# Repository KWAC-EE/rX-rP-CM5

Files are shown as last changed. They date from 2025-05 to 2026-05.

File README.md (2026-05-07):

## rX-rP-CM5 ##
**Radxa-rPi CM5 Compatibility Layer**






The Radxa and RaspberryPi CM5s have much in common, but the pinout between them differs. Functionally, the Radxa's RK3588 outperforms Broadcom's BCM2712 in most benchmarks (at least those i'm interested in):
[Benchmarks seen here](https://gadgetversus.com/processor/rockchip-rk3588s-vs-broadcom-bcm2712/)

Native GPU video encode and decode makes the Radxa far more ideal to use as the core of a media server, and local AI acceleration should allow a more energy efficient means of driving my smarthome devices without needing to ping a distal server.

Physically, the Radxa CM5 is more compatible with rPi CM4 carriers than it is with those built for the rPiCM5.
The CM4 wasn't received as enthusatically by developers as the CM5, so more custom carriers are being built to take advantage of the added USB3 functionality.
For that reason, i designed an adapter to transpose the USB3 lanes from the auxilary mezzanine connector on the Radxa to the corresponding pinout on the RaspberryPi variant.

This design includes automatic switching via MUX so the transposed lanes are allocated properly during flashing vs normal operation. CC resistors & VBus_Enable pull-ups have been added for designs which use those pins.

# Project design files
PCBAs are designed in Altium 22 & 25. This is a paid software platform for professionals, and viewer licenses can be requested from the developers.

Design references can also be found as PDFs for those who wish to rebuild segments of the design themselves.

# PCBA exports/ Manufacturer files
Designs have been exported as Gerbers with Pick&Place & BOM files such that they may be fully assembled by prototypers such as JLC-PCB, PCB-Way and the like.
Simply upload the zipped project export folder for the PCB, then the internal XLXS/CSV component-level assembly.

# License
Copyright Kurt Widhalm/@KWAC-EE 2025
This source describes Open Hardware and is licensed under the CERN-OHL-P v2

You may redistribute and modify this documentation and make products using it under the terms of the CERN-OHL-P v2 (https:/cern.ch/cern-ohl). This documentation is distributed WITHOUT ANY EXPRESS OR IMPLIED WARRANTY, INCLUDING OF MERCHANTABILITY, SATISFACTORY QUALITY AND FITNESS FOR A PARTICULAR PURPOSE. Please see the CERN-OHL-P v2 for applicable conditions

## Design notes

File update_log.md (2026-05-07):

*10/16/2025*
Samples of X2 arrived, as did a fresh CM5 from Radxa.
As hoped, the USB-C port allows the device to be programmed independently.
There are a few bugs in the transposition, at least in the carrier I design to pair with this.
The primary USB3 lane from the auxilary port is transposed to the USB3-1 channel pads of the Raspberry pi CM5 carrier, and downstream devices fully enumerate and function.
The USB-C channel, however, doesn't appear to be behaving correctly, at least not on my current OS & hardware.
Similarly, the USB2 lane that is transposed to the OTG pads doesn't appear to initialize the downstream hub.
I'll continue testing by using a real CM5 IO board from raspberry pi soon.

**<11:30pm>**
ok, I know what I did now. flipped the polarity between the otg & USB-C d+/- nets. dislexia strikes again...

you know what they say: third rev's the charm. dammit....

*11/17/2025*
X3 samples are in. USB2 and USB3-1 channels work as intended, and the onboard USB-C(2.0) port allows flashing of the module; USB3-0, which is derived from the Type-C on header J3, will not enumerate connected devices through OTG/Host mode. May be from I2C port controller, still debugging

*2/20/2026*
X4 design is done. giving up on using the OTG port to drive a separate USB3 channel, and instead decided to split the known working USB3 channel with a hub. Will this reduce overall bandwidth? Yes, but for my application, i doubt it will be noticable.
I'll order samples when i place another order for other parts.

*3/27/2026*
Shouldn't have given up on X3 so quickly... Did a bit more experimenting. Lo and Behold, i needed to depop the FUSB chip completely, enter the Radxa OS configuration utility and manually set the OTG port to use only Host mode, and Tah-dah, it works exactly as intended. which is good, because there seems to be some interference caused by the hub on the X4 version that prevents the flashing utility from conntecting to the Emmc. So if you were planning on using any version of this design, i recommend starting from X3, removing the FUSB U1 component, and configuring it within the device tree.

*5/7/2026*
I just widdled it down for rev X5 to make use of what I learned from working on X3. Mechanically, the addition of the USB-C port was a hinderance; it got in the way of a few hardware enclosures, so i wasn't cleanly able to test compatibility with some custom carriers.
Electrically, i think the MUX config will function better so I can flash the EEprom of the SoM without the extra connector. Furthermore, i needed to add pull-ups for the VBus-enable pin so the current regulator on the Pi Cm5 IO board would turn on without bodging at start-up.
IDk when i'll be able to order samples. I really want to deploy one of these units so i can set up my Arm64 Nas, but the expense is hard to justify without additional parts to order with it.

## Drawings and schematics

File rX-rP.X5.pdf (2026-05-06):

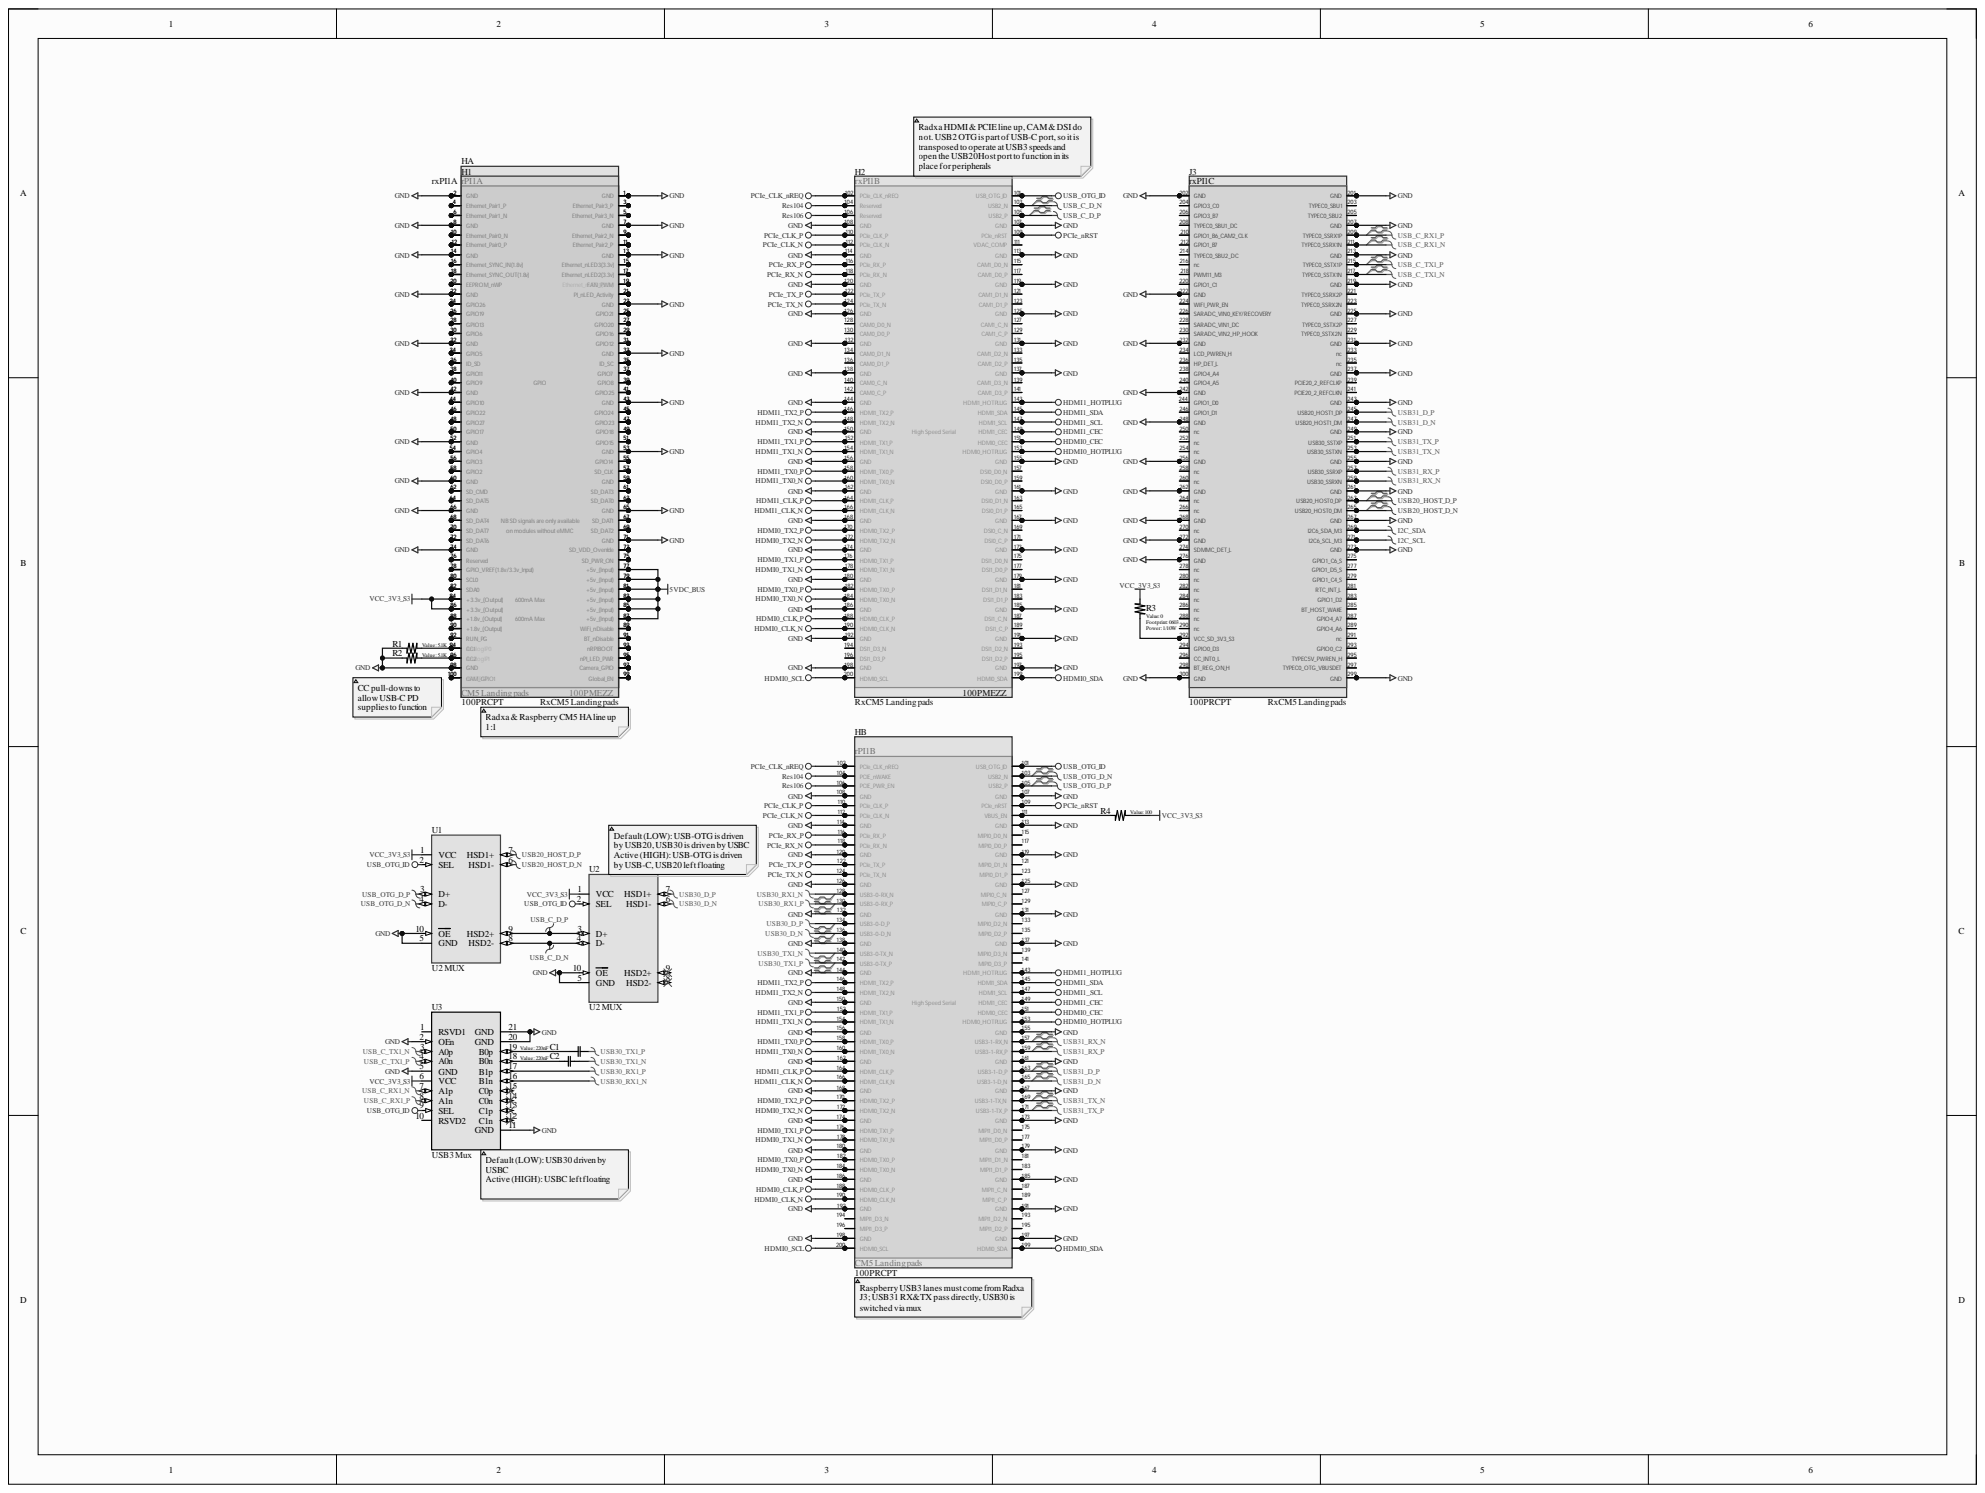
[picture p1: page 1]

Radxa HDMI &PCIEline up,CAM&DSI do
not. USB2 OTG is part of USB-C port,so itis
transposed to operate atUSB3 speeds and
open the USB20Hostportto function in its
place for peripherals

NB SD signals are only available

on modules without eMMC

Default(LOW):USB-OTG is driven
by USB20, USB30 is driven by USBC
Active (HIGH):USB-OTG is driven
by USB-C,USB20 leftfloating

Default(LOW):USB30 driven by
USBC
Active (HIGH):USBC leftfloating

CM5 Landingpads
100PRCPT
Raspberry USB3 lanesmust come fromRadxa
J3;USB31RX&TX pass directly, USB30 is
switched via mux

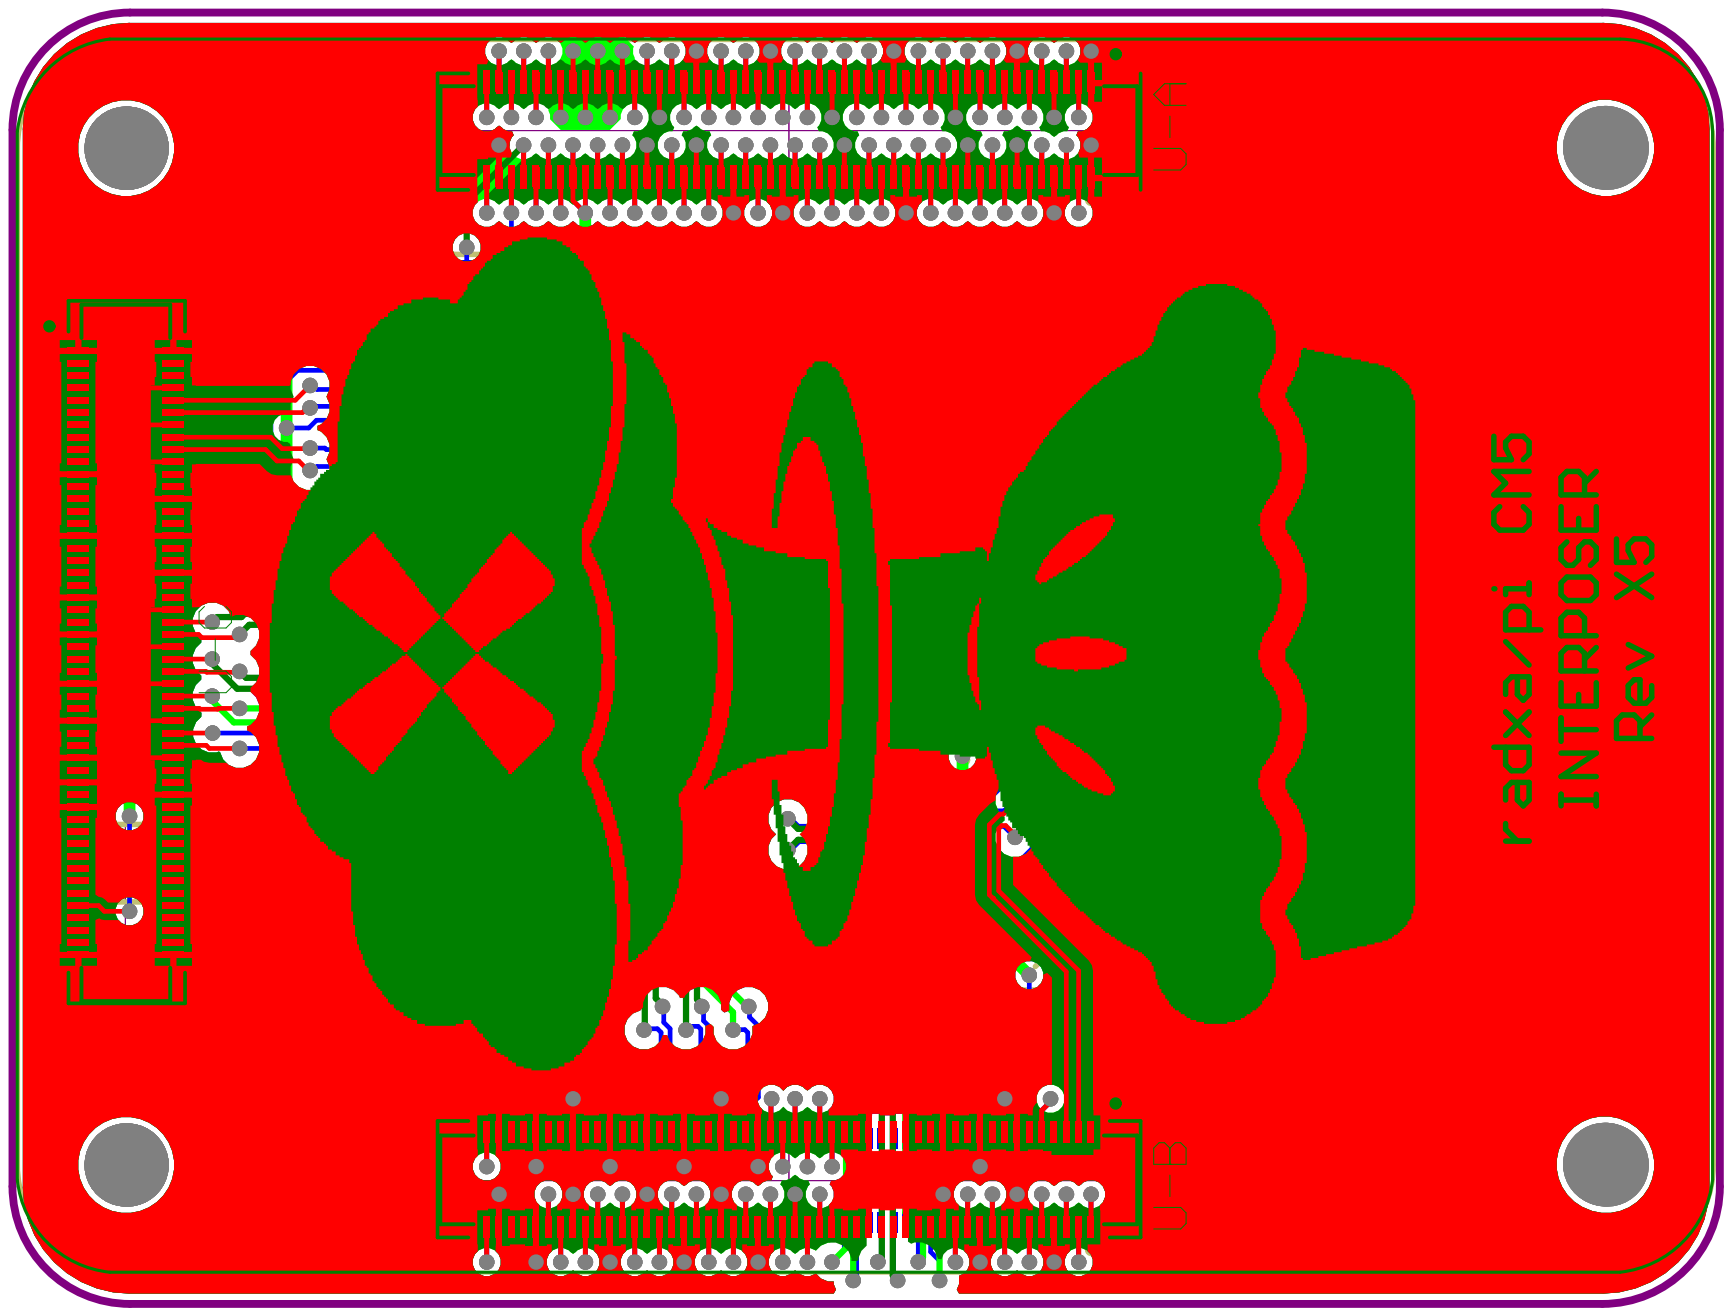
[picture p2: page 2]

Designator | Footprint | Value | LCSCPN
C1 | 0603 | 220nF
C2 | 0603 | 220nF
H1 | DF40C-100DS-0.4V(51) | | C597931
H2 | DF40C-100DS-0.4V(51) | | C597931
HA | DF40C-100DP-0.4V(51) | | C19089239
HB | DF40C-100DP-0.4V(51) | | C19089239
J3 | DF40C-100DS-0.4V(51) | | C597931
R1 | 0603 | 5.1K
R2 | 0603 | 5.1K
R3 | 0603 | 0
R4 | 0603 | 100
rPI1 | rP-200P-CM-REP(top)
rxPI1 | RX-300P-CM-FTPD
U1 | MSOP-10 | | C11355
U2 | MSOP-10 | | C11355
U3 | QFN50P450X250X100-21N | | C2869871

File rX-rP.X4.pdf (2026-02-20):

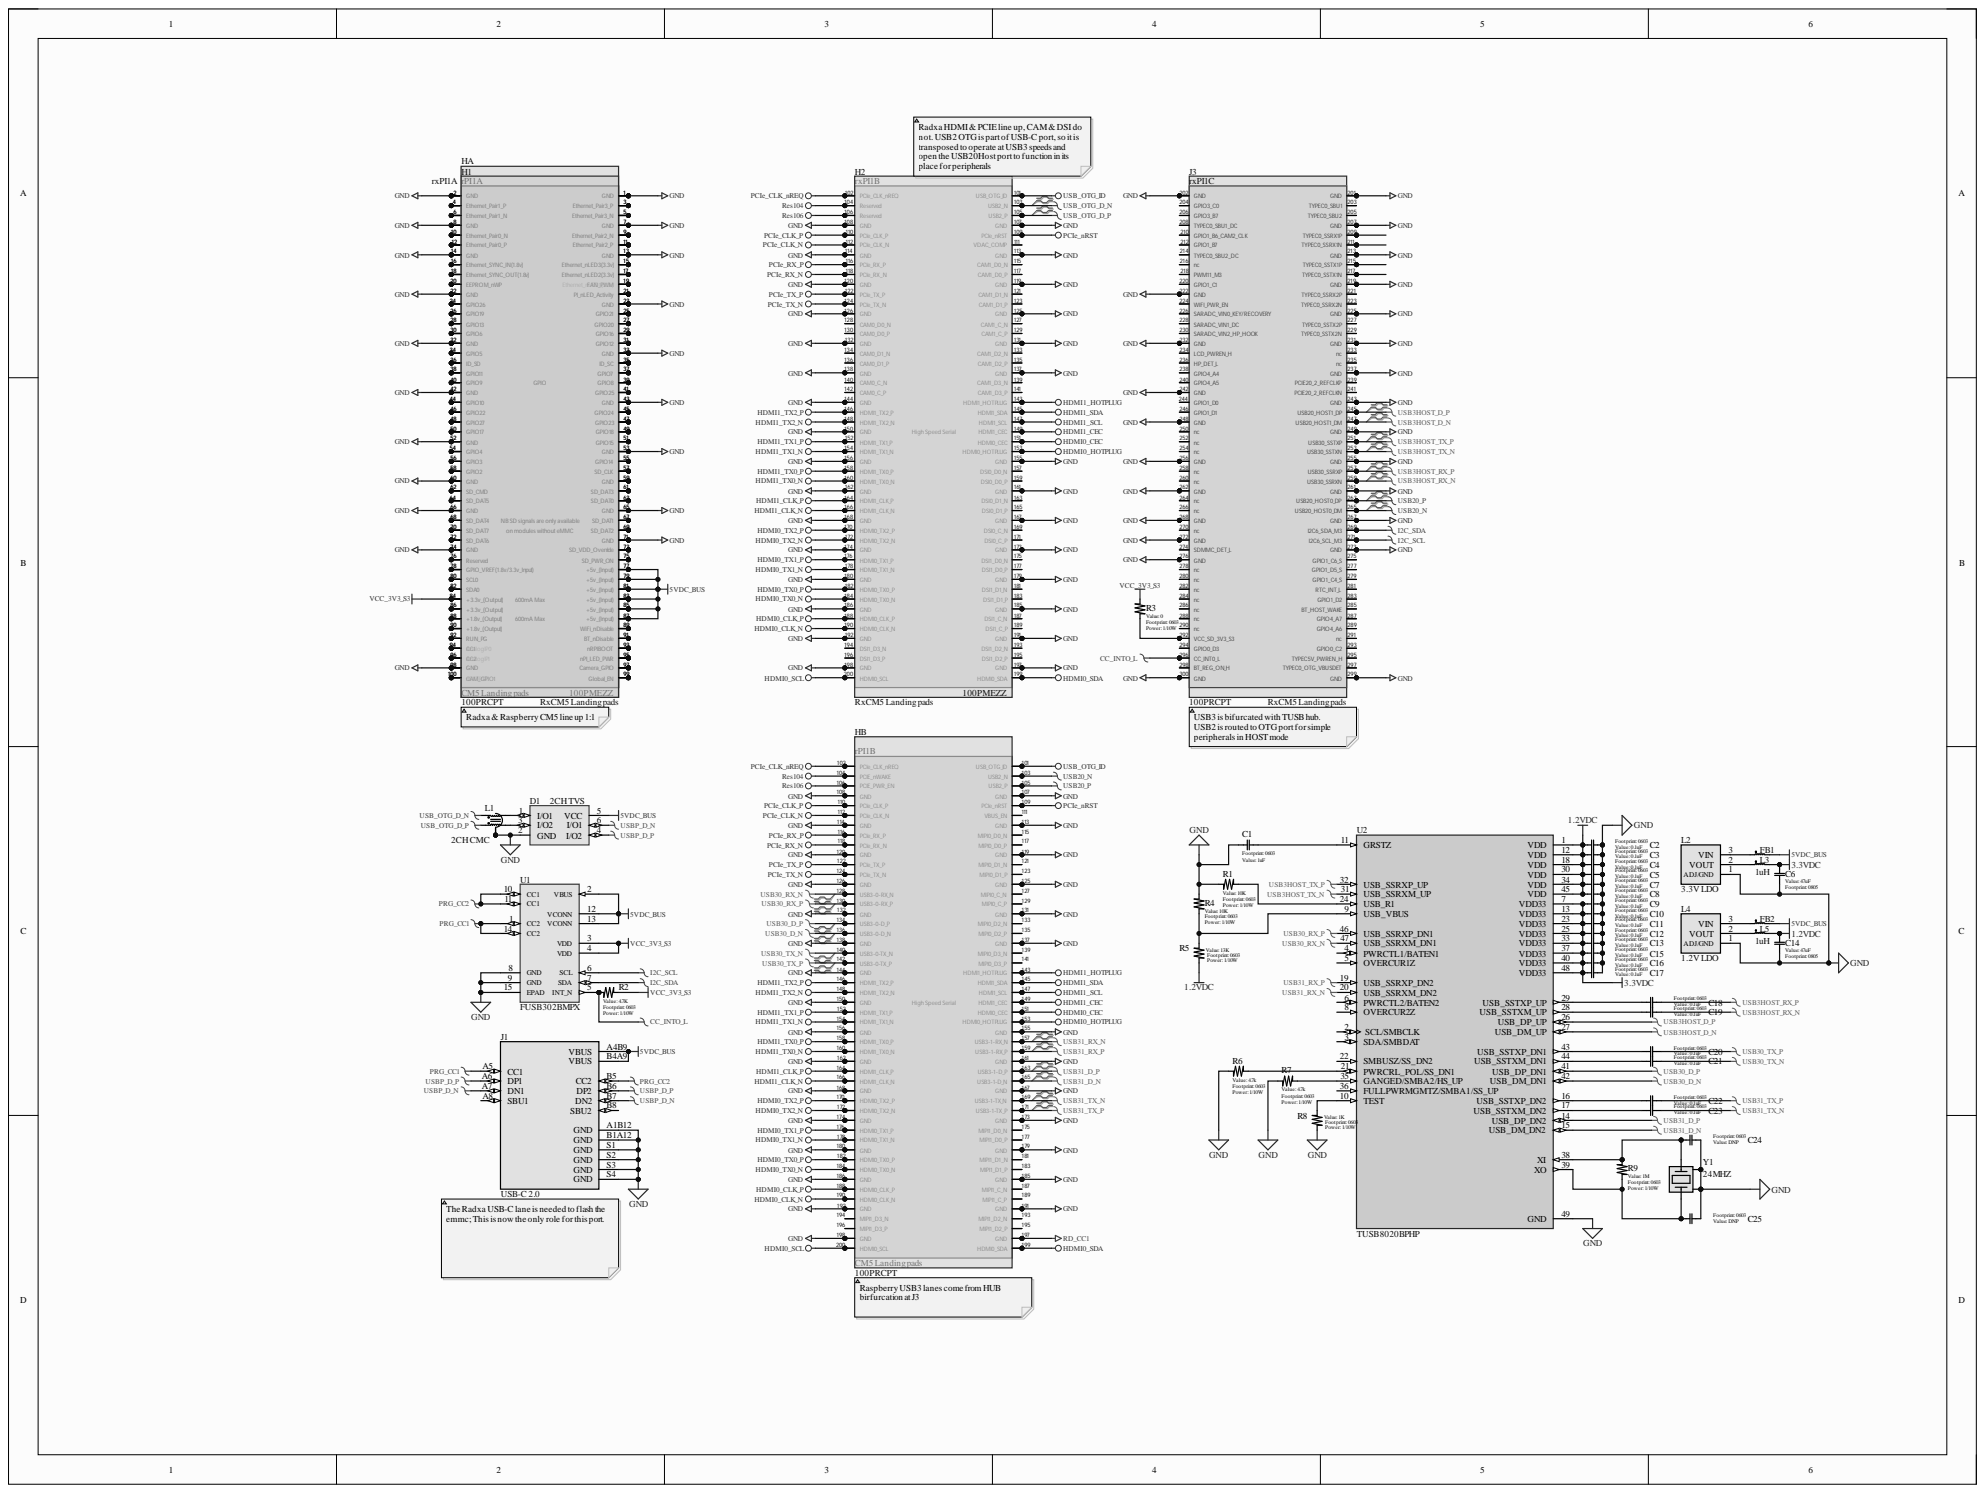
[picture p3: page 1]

GND GND GND GND GND GND GND GND GND GND GND

GND GND GND GND GND GND GND GND GND

GND GND GND GND GND GND GND

GND GND GND GND GND GND GND GND

GND GND GND GND GND GND GND GND GND GND GND GND GND

GND GND GND GND GND GND GND GND GND GND GND GND HDMI0_

GND GND GND GND GND GND GND GND GND GND GND GND GND GND GND

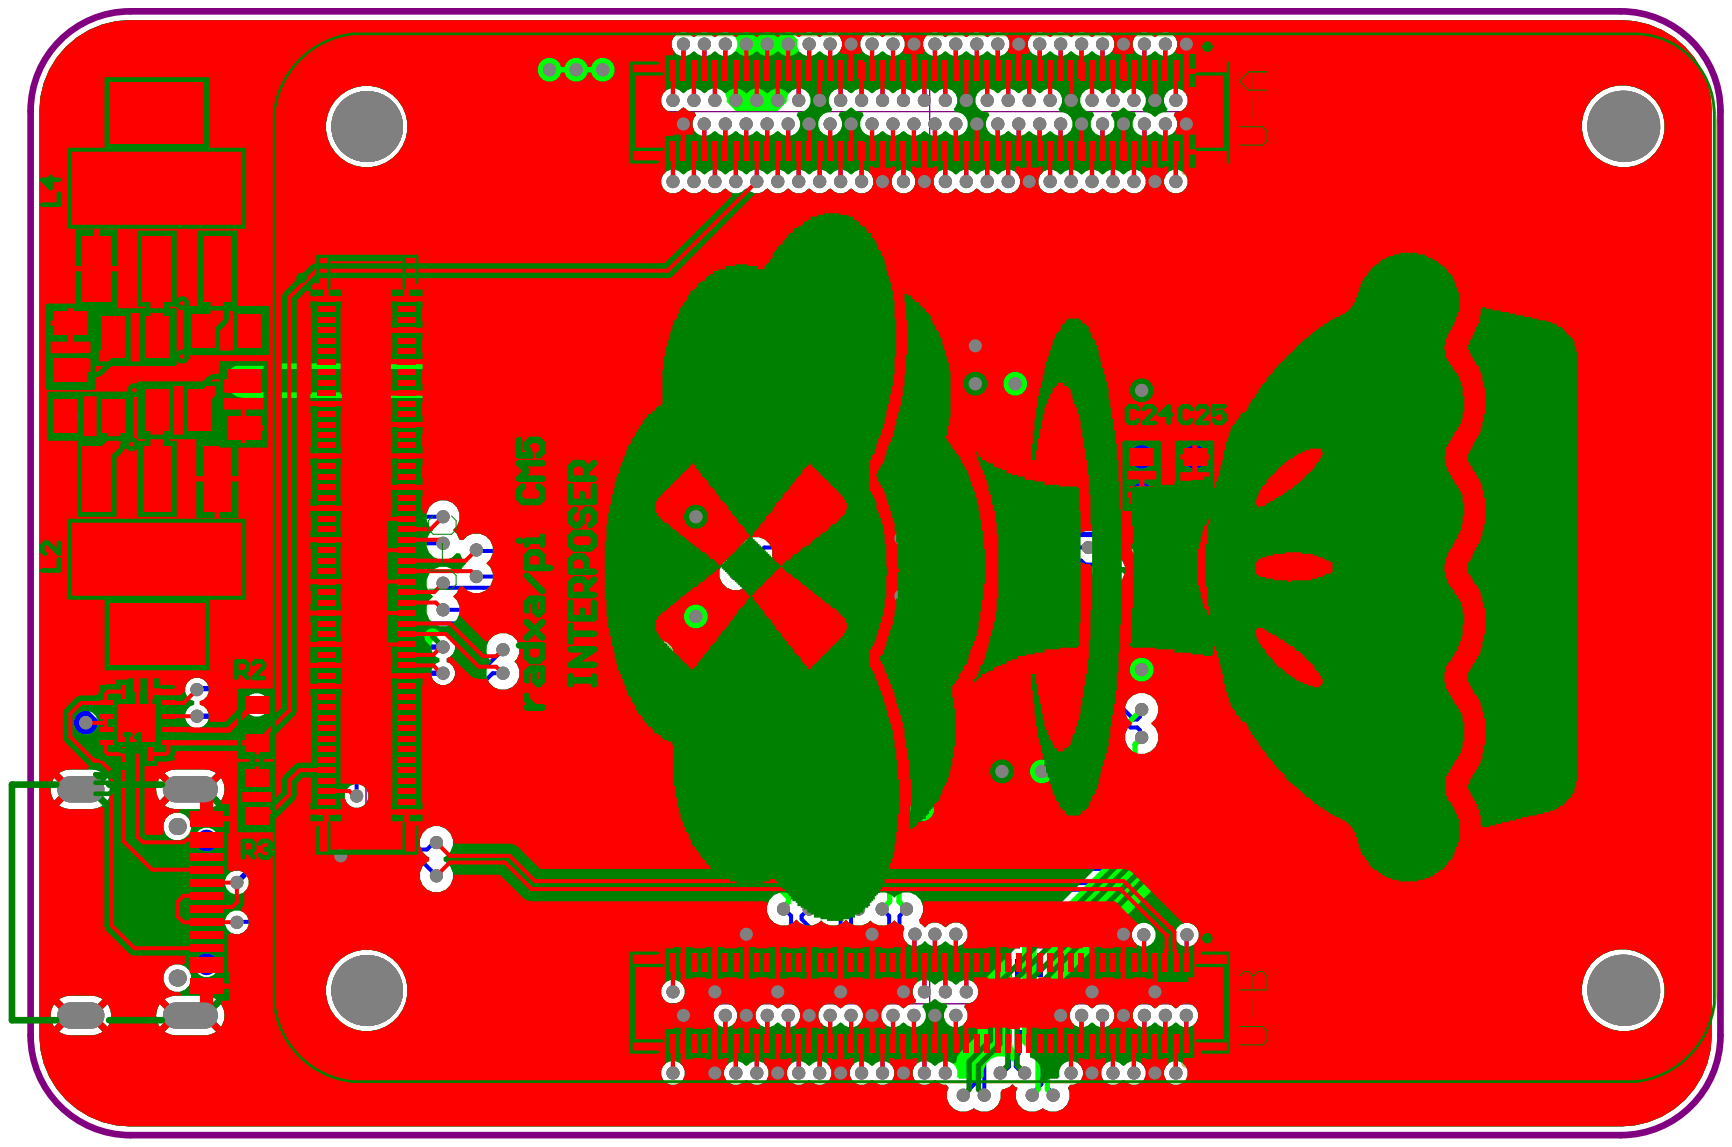
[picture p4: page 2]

Designator | Footprint | Value | LCSCPN
C1 | 0603 | 1uF
C2 | 0603 | 0.1uF
C3 | 0603 | 0.1uF
C4 | 0603 | 0.1uF
C5 | 0603 | 0.1uF
C6 | 0805 | 47uF
C7 | 0603 | 0.1uF
C8 | 0603 | 0.1uF
C9 | 0603 | 0.1uF
C10 | 0603 | 0.1uF
C11 | 0603 | 0.1uF
C12 | 0603 | 0.1uF
C13 | 0603 | 0.1uF
C14 | 0805 | 47uF
C15 | 0603 | 0.1uF
C16 | 0603 | 0.1uF
C17 | 0603 | 0.1uF
C18 | 0603 | 0.1uF
C19 | 0603 | 0.1uF
C20 | 0603 | 0.1uF
C21 | 0603 | 0.1uF
C22 | 0603 | 0.1uF
C23 | 0603 | 0.1uF
C24 | 0603 | DNP
C25 | 0603 | DNP
D1 | FP-SOT886-MFG | 1pF | C478118
FB1 | 0805
FB2 | 0805
H1 | DF40C-100DS-0.4V(51) | | C597931
H2 | DF40C-100DS-0.4V(51) | | C597931
HA | DF40C-100DP-0.4V(51) | | C19089239
HB | DF40C-100DP-0.4V(51) | | C19089239
J1 | GT-USB-7010ASV | | C2988369
J3 | DF40C-100DS-0.4V(51) | | C597931
L1 | SMD-6-2CH | | C396460
L2 | SOT-223-3 | | C326523
L3 | 0806
L4 | SOT-223-3 | | C277890
L5 | 0806
R1 | 0603 | 10K
R2 | 0603 | 4.7K
R3 | 0603 | 0
R4 | 0603 | 10K
R5 | 0603 | 13K
R6 | 0603 | 4.7k
R7 | 0603 | 4.7k
R8 | 0603 | 1K
R9 | 0603 | 1M
rPI1 | rP-200P-CM-REP(top)
rxPI1 | RX-300P-CM-FTPD
U1 | MLP14_2P5X2P5_ONS-L | | C132291
U2 | HTQFP-48(7x7) | | C205982
Y1 | SMD2520-4P | | C7294628
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

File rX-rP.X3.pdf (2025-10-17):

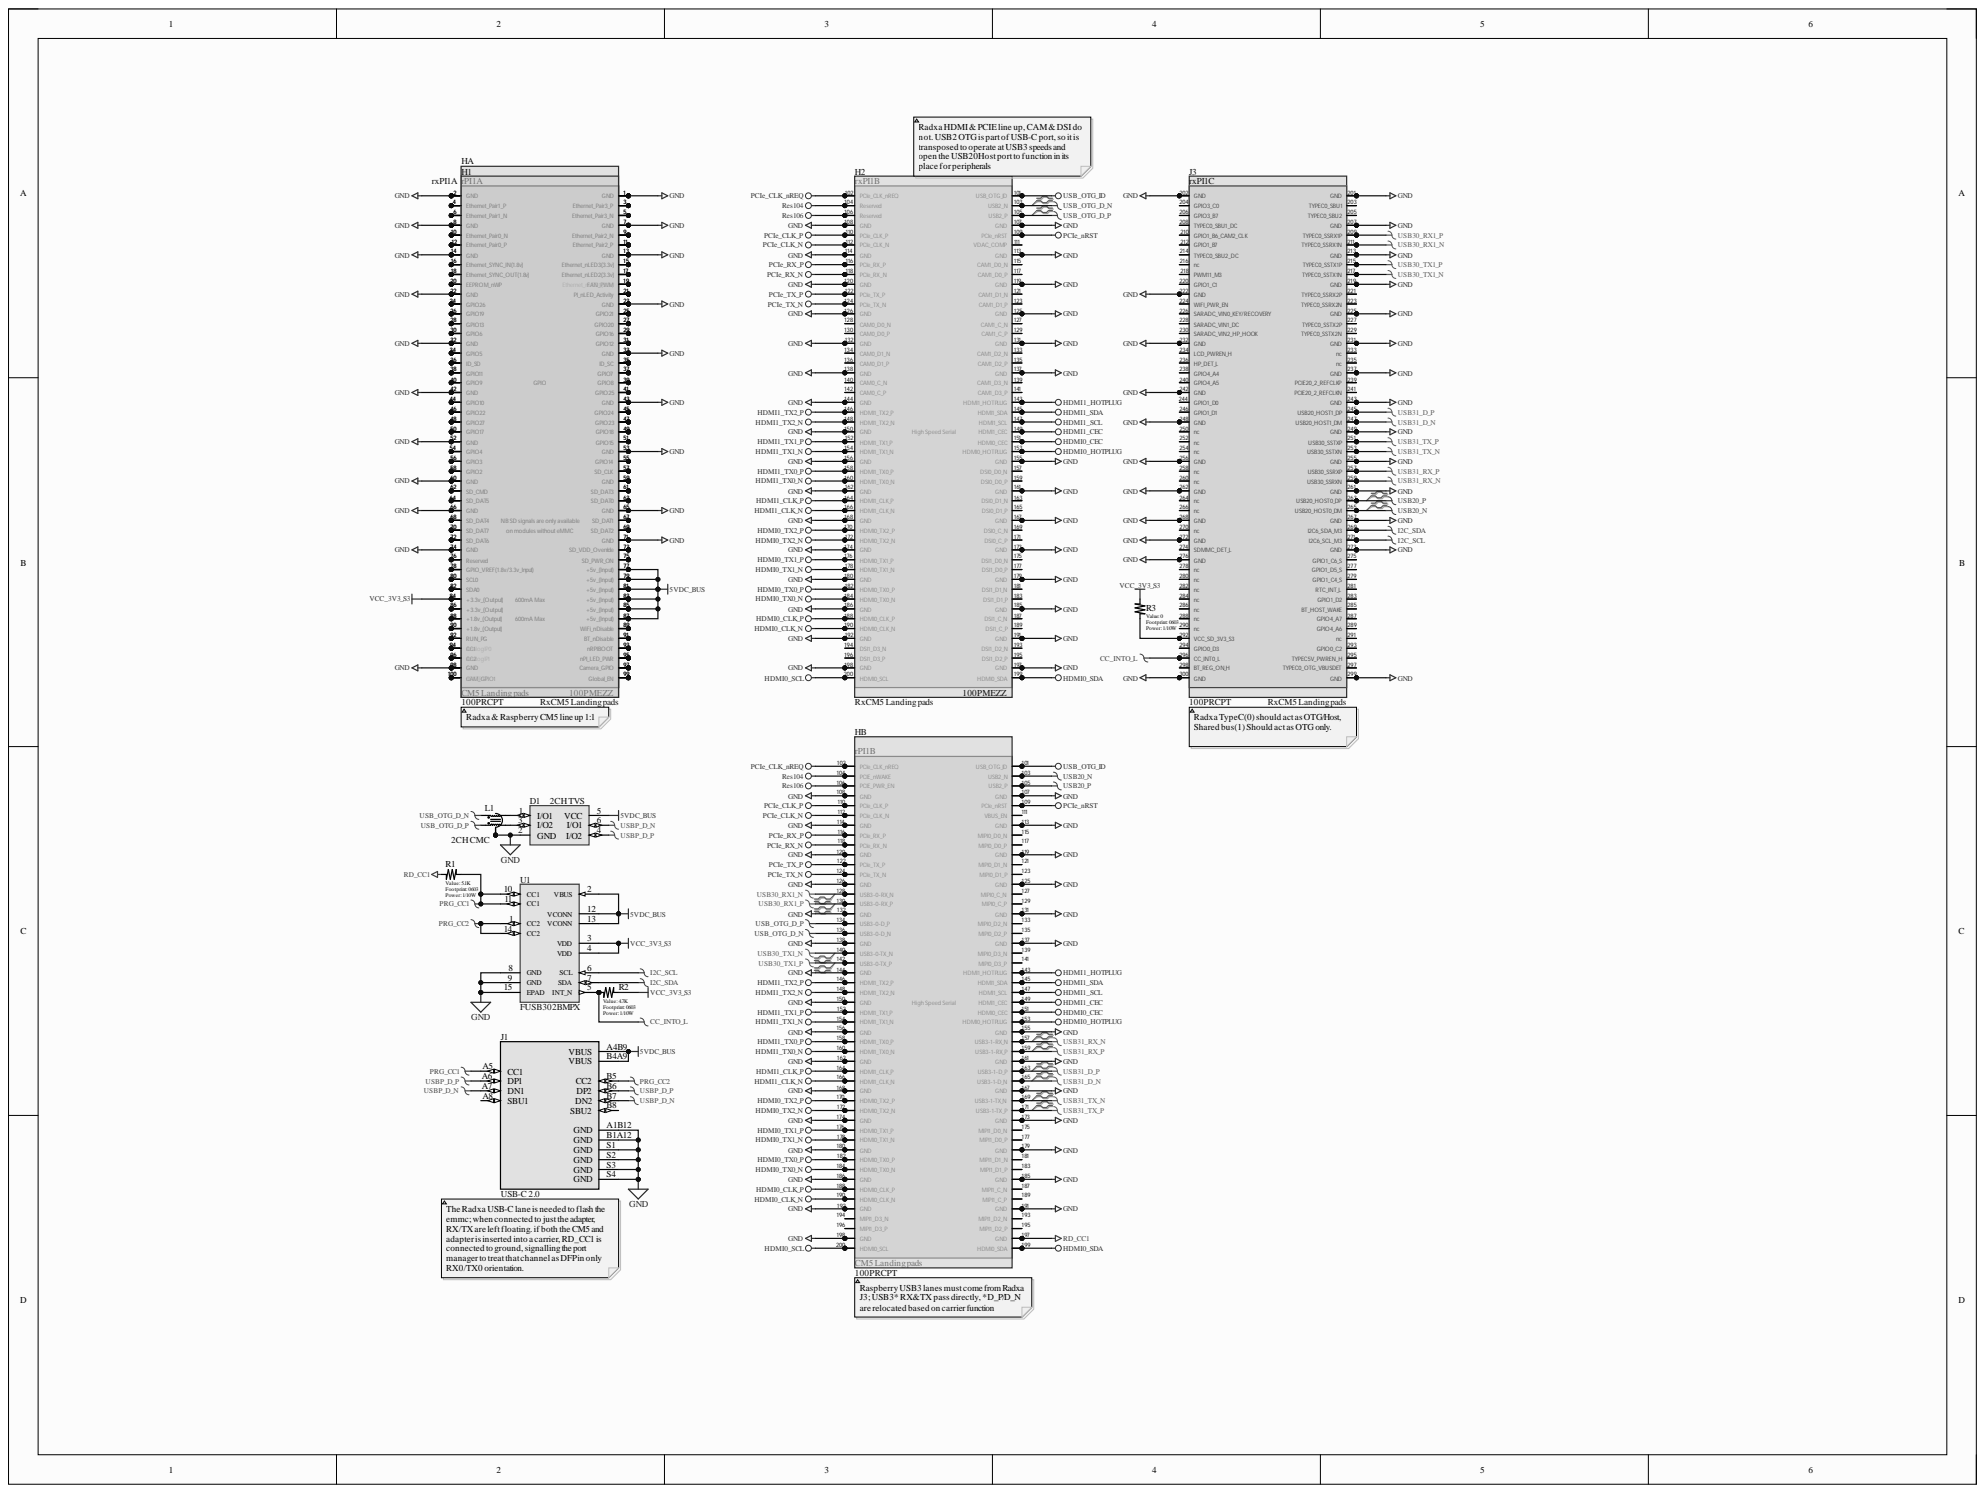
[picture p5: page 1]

Radxa HDMI &PCIEline up,CAM&DSI do
not. USB2 OTG is part of USB-C port,so itis
transposed to operate atUSB3 speeds and
open the USB20Hostportto function in its
place for peripherals

NB SD signals are only available

on modules without eMMC

100PRCPT
Radxa TypeC(0) should act asOTG/Host,
Shared bus(1) Should act asOTG only.

TheRadxa USB-C lane is needed to flash the
emmc;when connected to justthe adapter,
RX/TX are leftfloating. if both theCM5 and
adapter isinserted into a carrier,RD_CC1 is
connected to ground,signallingthe port
manager to treatthat channel asDFPin only
RX0/TX0 orientation.

CM5 Landingpads
Raspberry USB3 lanesmust come fromRadxa
J3;USB3*RX&TX pass directly, *D_P/D_N
are relocated based on carrier function

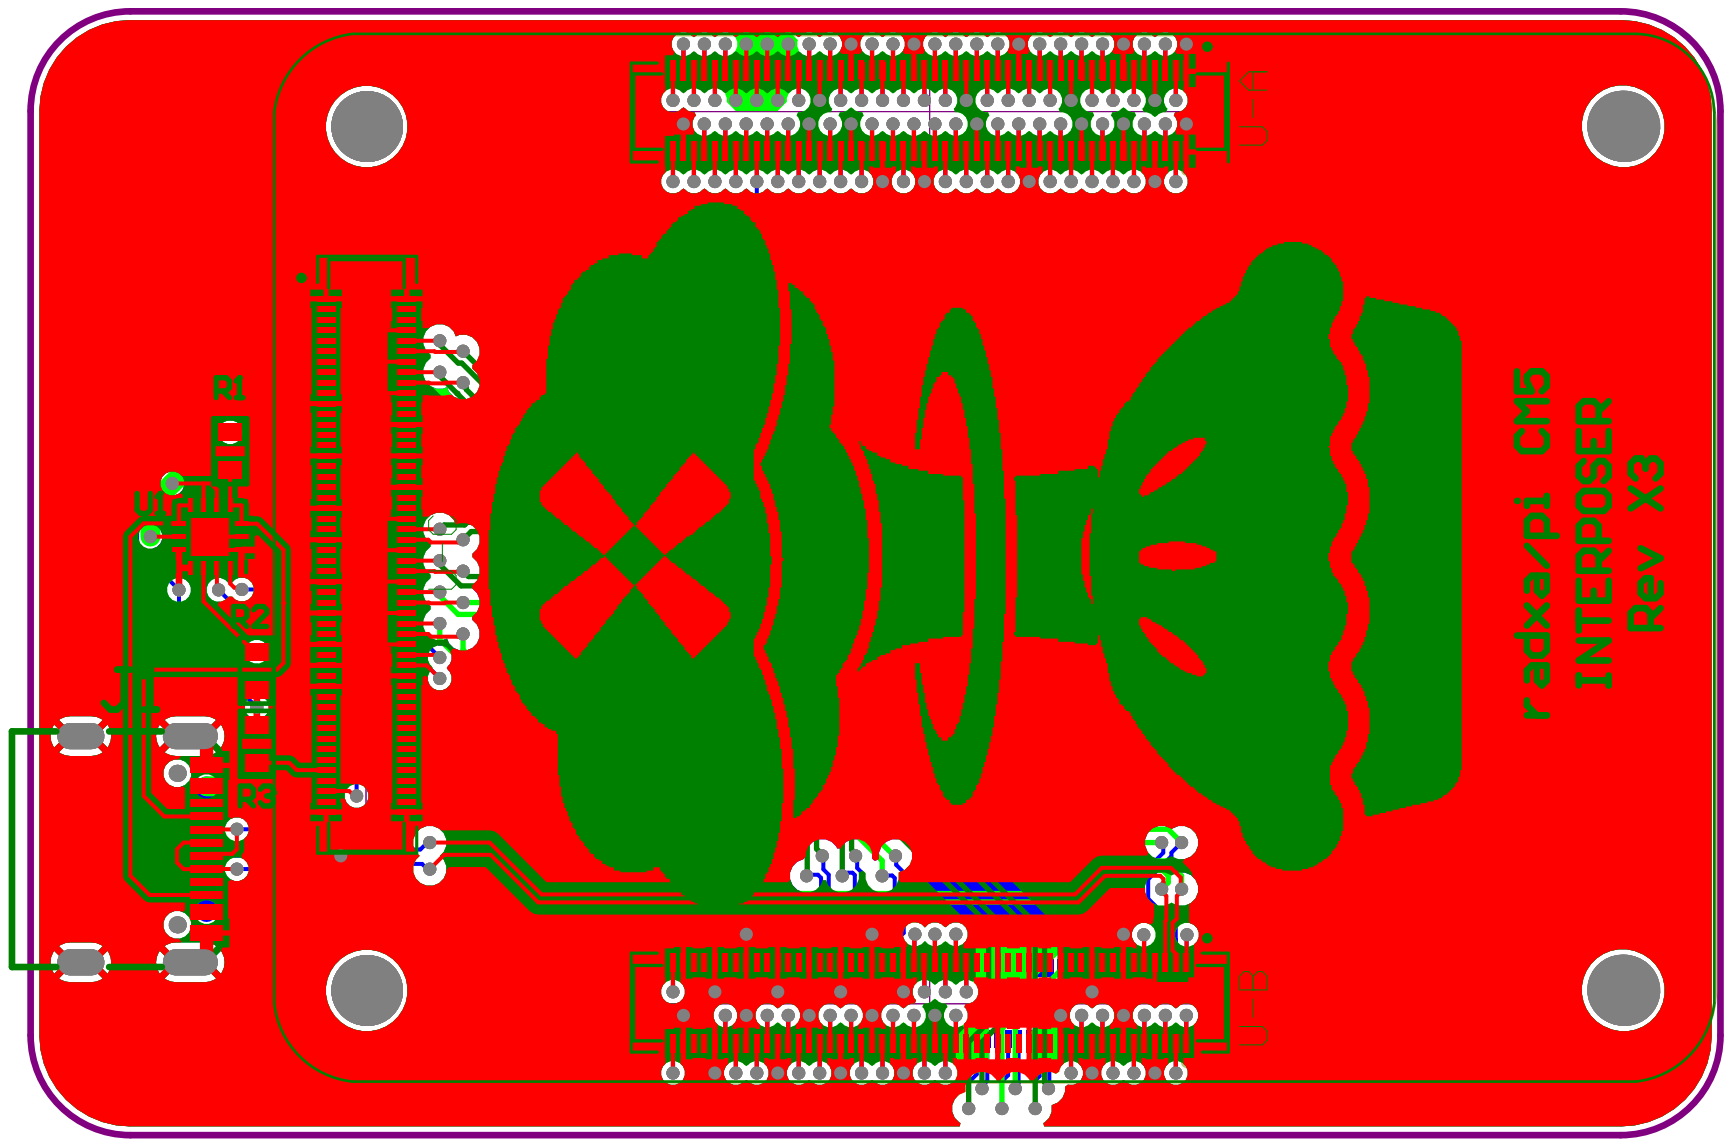
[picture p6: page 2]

Designator | Footprint | Value | LCSCPN
D1 | FP-SOT886-MFG | 1pF | C478118
H1 | DF40C-100DS-0.4V(51) | | C597931
H2 | DF40C-100DS-0.4V(51) | | C597931
HA | DF40C-100DP-0.4V(51) | | C19089239
HB | DF40C-100DP-0.4V(51) | | C19089239
J1 | GT-USB-7010ASV | | C2988369
J3 | DF40C-100DS-0.4V(51) | | C597931
L1 | SMD-6-2CH | | C396460
R1 | 0603 | 5.1K
R2 | 0603 | 4.7K
R3 | 0603 | 0
rPI1 | rP-200P-CM-REP(top)
rxPI1 | RX-300P-CM-FTPD
U1 | MLP14_2P5X2P5_ONS-L | | C132291

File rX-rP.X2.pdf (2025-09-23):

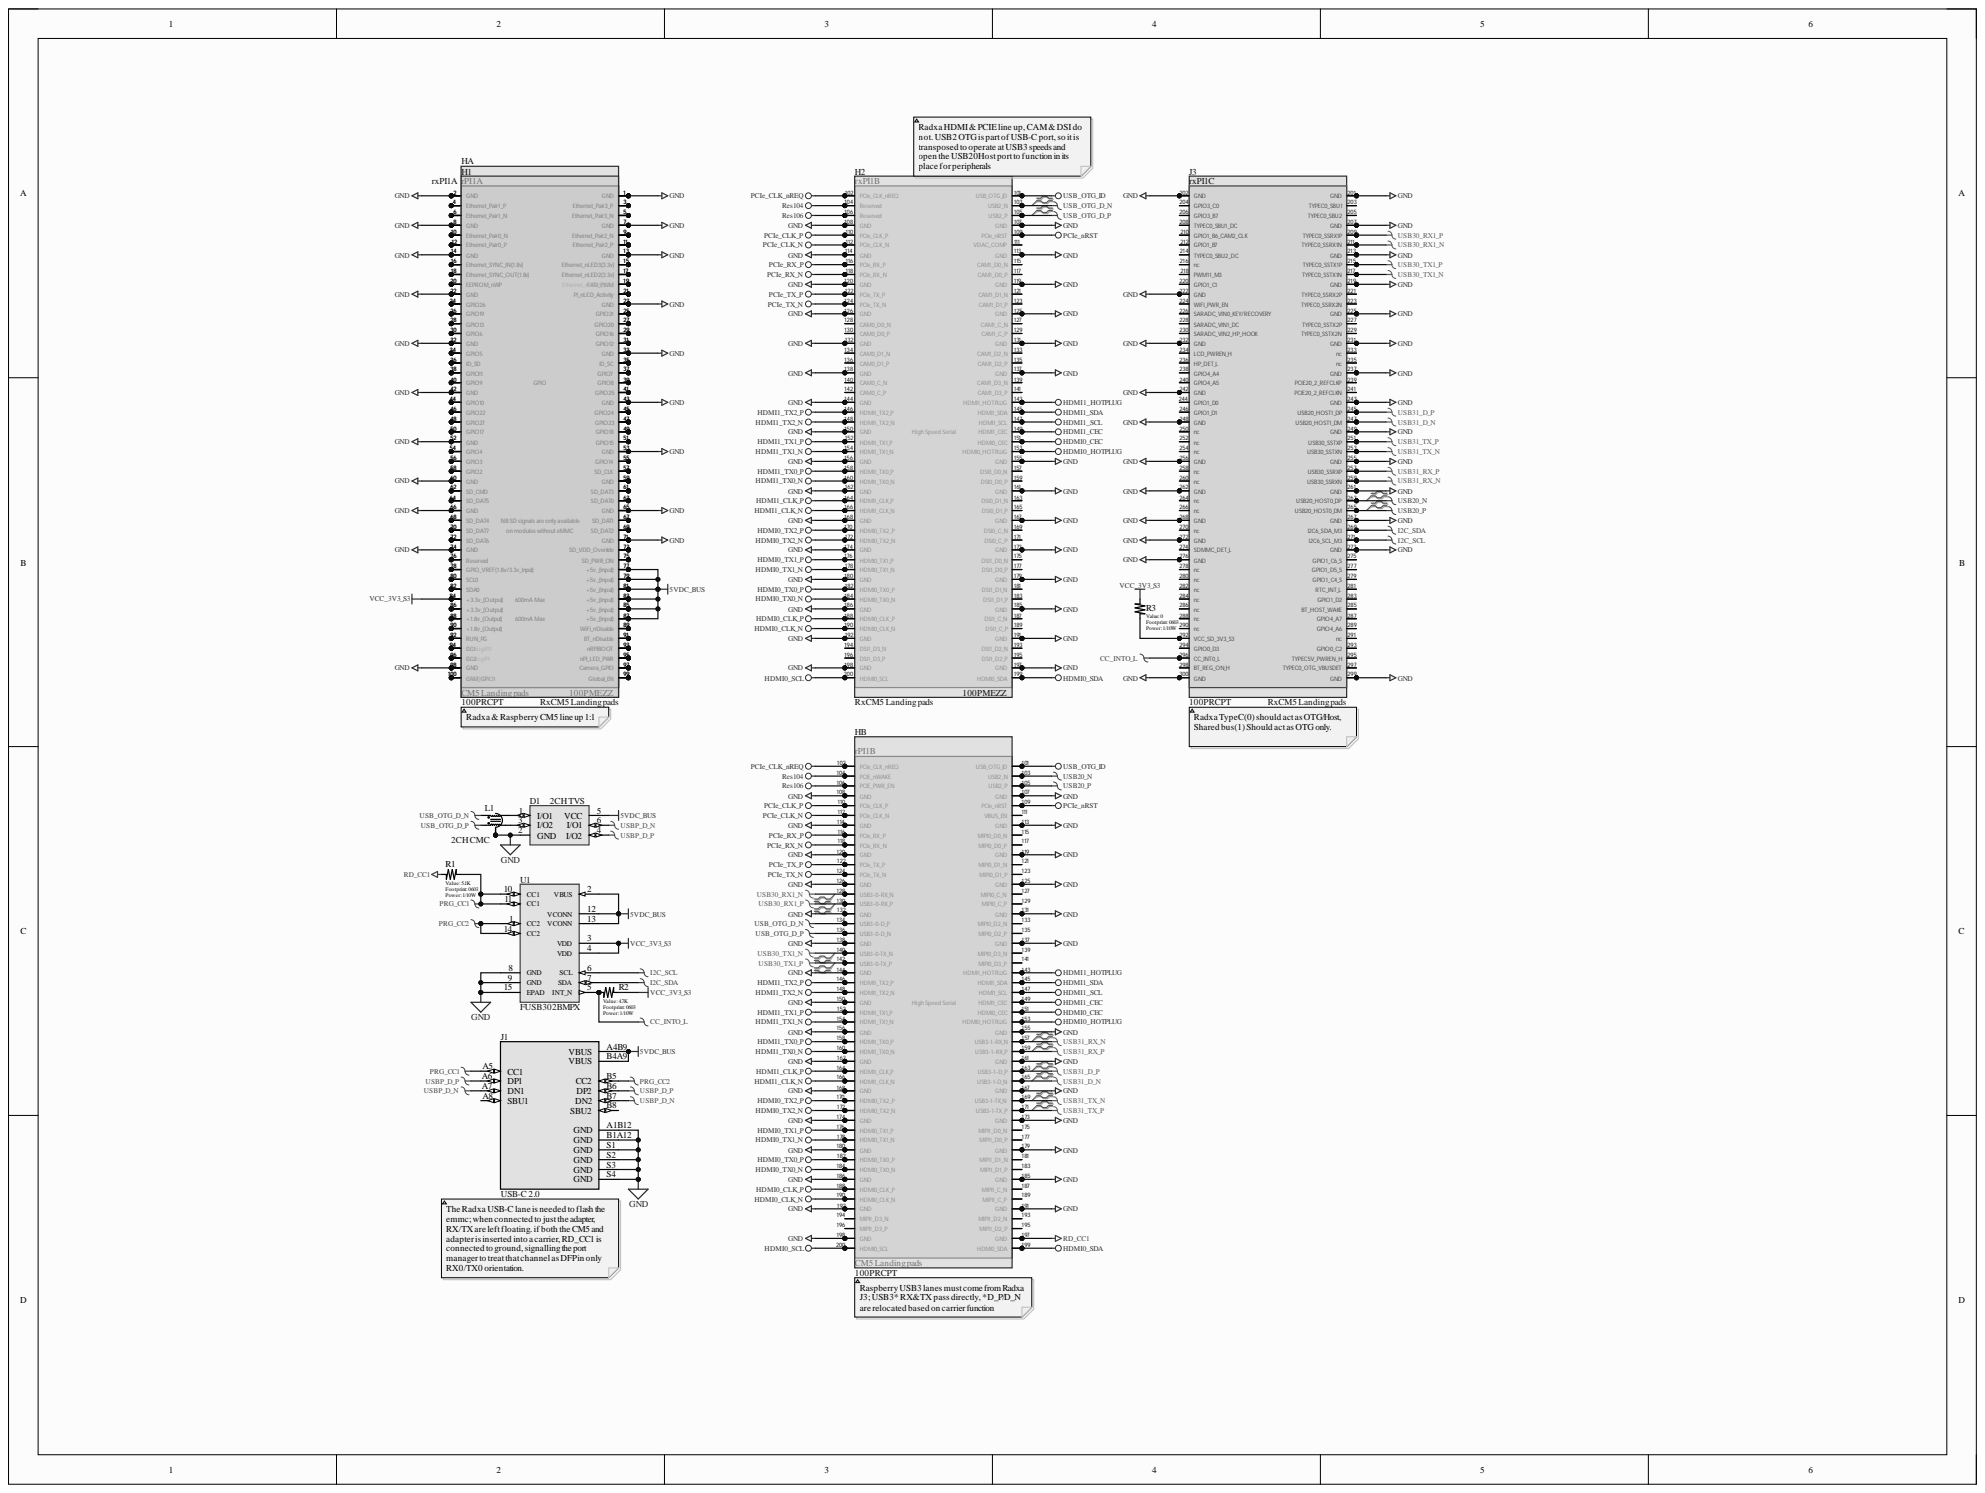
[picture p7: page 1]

Radxa HDMI &PCIEline up,CAM&DSI do
not. USB2 OTG is part of USB-C port,so itis
transposed to operate atUSB3 speeds and
open the USB20Hostportto function in its
place for peripherals

NB SD signals are only available

on modules without eMMC

100PRCPT
Radxa TypeC(0) should act asOTG/Host,
Shared bus(1) Should act asOTG only.

TheRadxa USB-C lane is needed to flash the
emmc;when connected to justthe adapter,
RX/TX are leftfloating. if both theCM5 and
adapter isinserted into a carrier,RD_CC1 is
connected to ground,signallingthe port
manager to treatthat channel asDFPin only
RX0/TX0 orientation.

CM5 Landingpads
Raspberry USB3 lanesmust come fromRadxa
J3;USB3*RX&TX pass directly, *D_P/D_N
are relocated based on carrier function

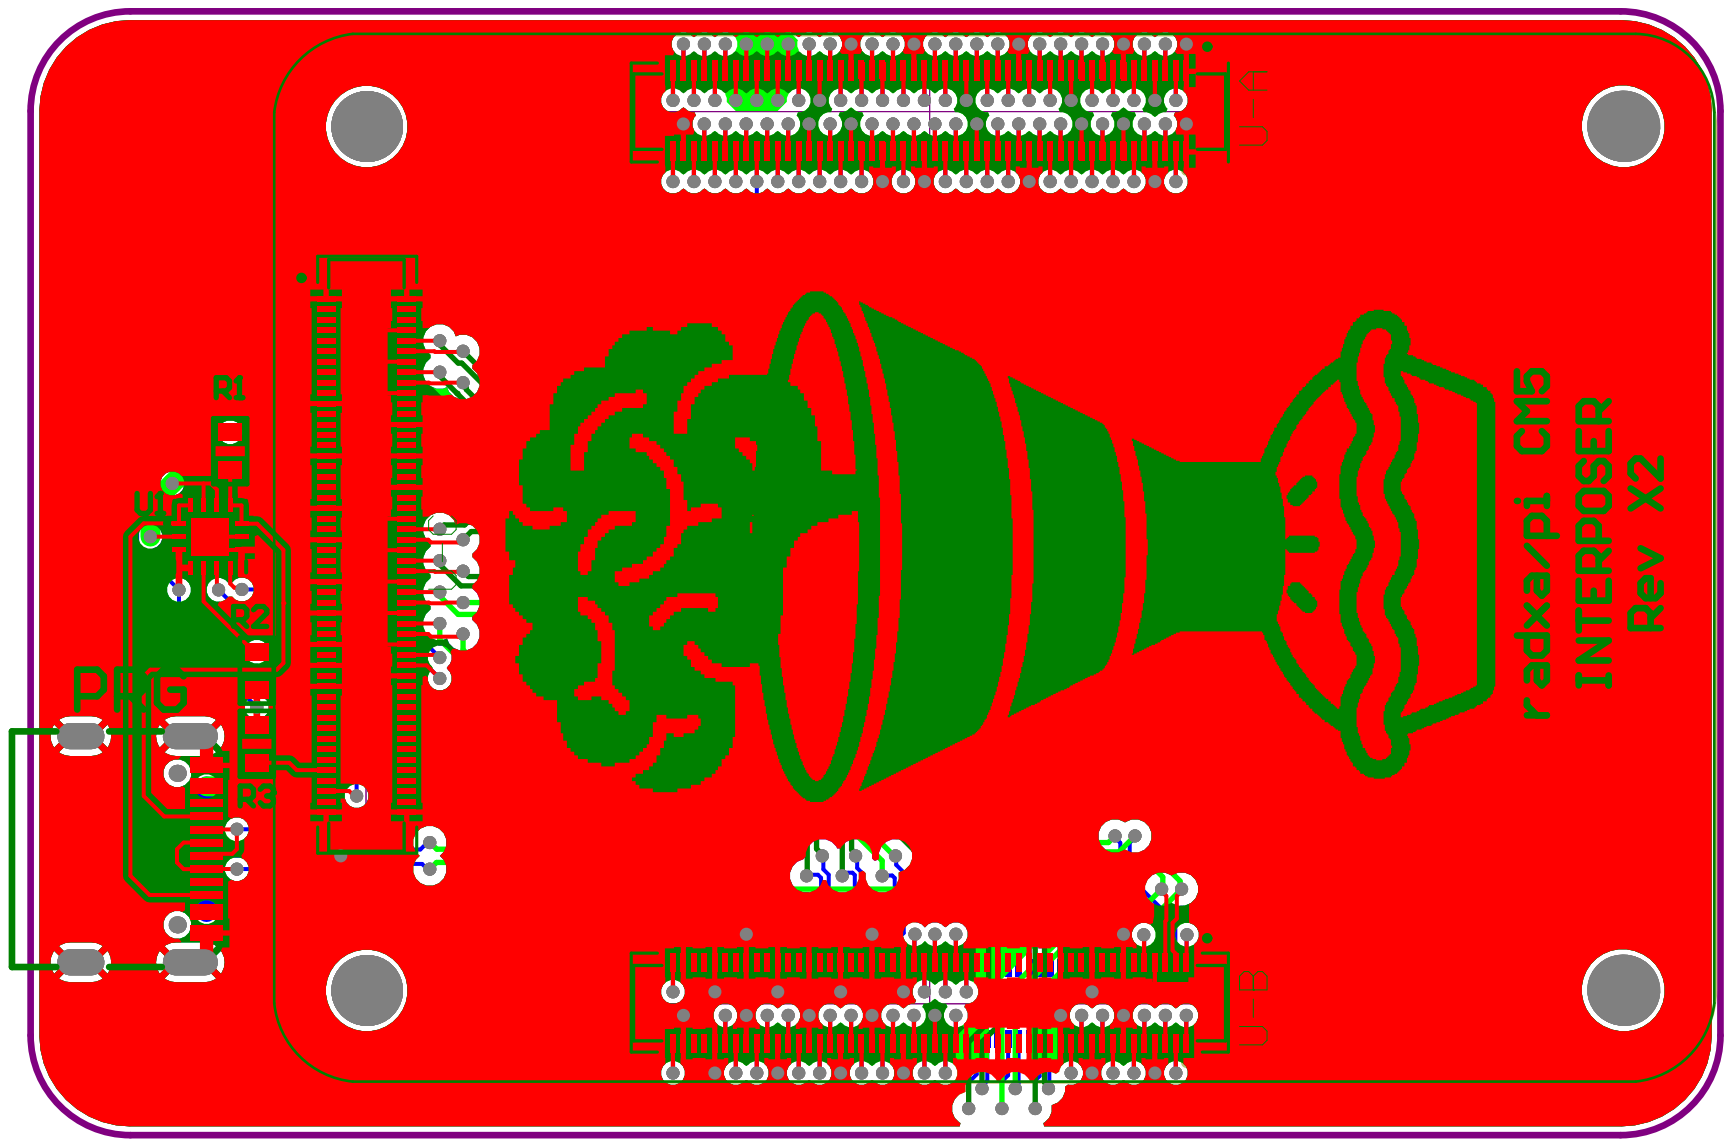
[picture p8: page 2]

Designator | Footprint | Value | LCSCPN
D1 | FP-SOT886-MFG | 1pF | C478118
H1 | DF40C-100DS-0.4V(51) | | C597931
H2 | DF40C-100DS-0.4V(51) | | C597931
HA | DF40C-100DP-0.4V(51) | | C19089239
HB | DF40C-100DP-0.4V(51) | | C19089239
J1 | GT-USB-7010ASV | | C2988369
J3 | DF40C-100DS-0.4V(51) | | C597931
L1 | SMD-6-2CH | | C396460
R1 | 0603 | 5.1K
R2 | 0603 | 4.7K
R3 | 0603 | 0
rPI1 | rP-200P-CM-REP(top)
rxPI1 | RX-300P-CM-FTPD
U1 | MLP14_2P5X2P5_ONS-L | | C132291

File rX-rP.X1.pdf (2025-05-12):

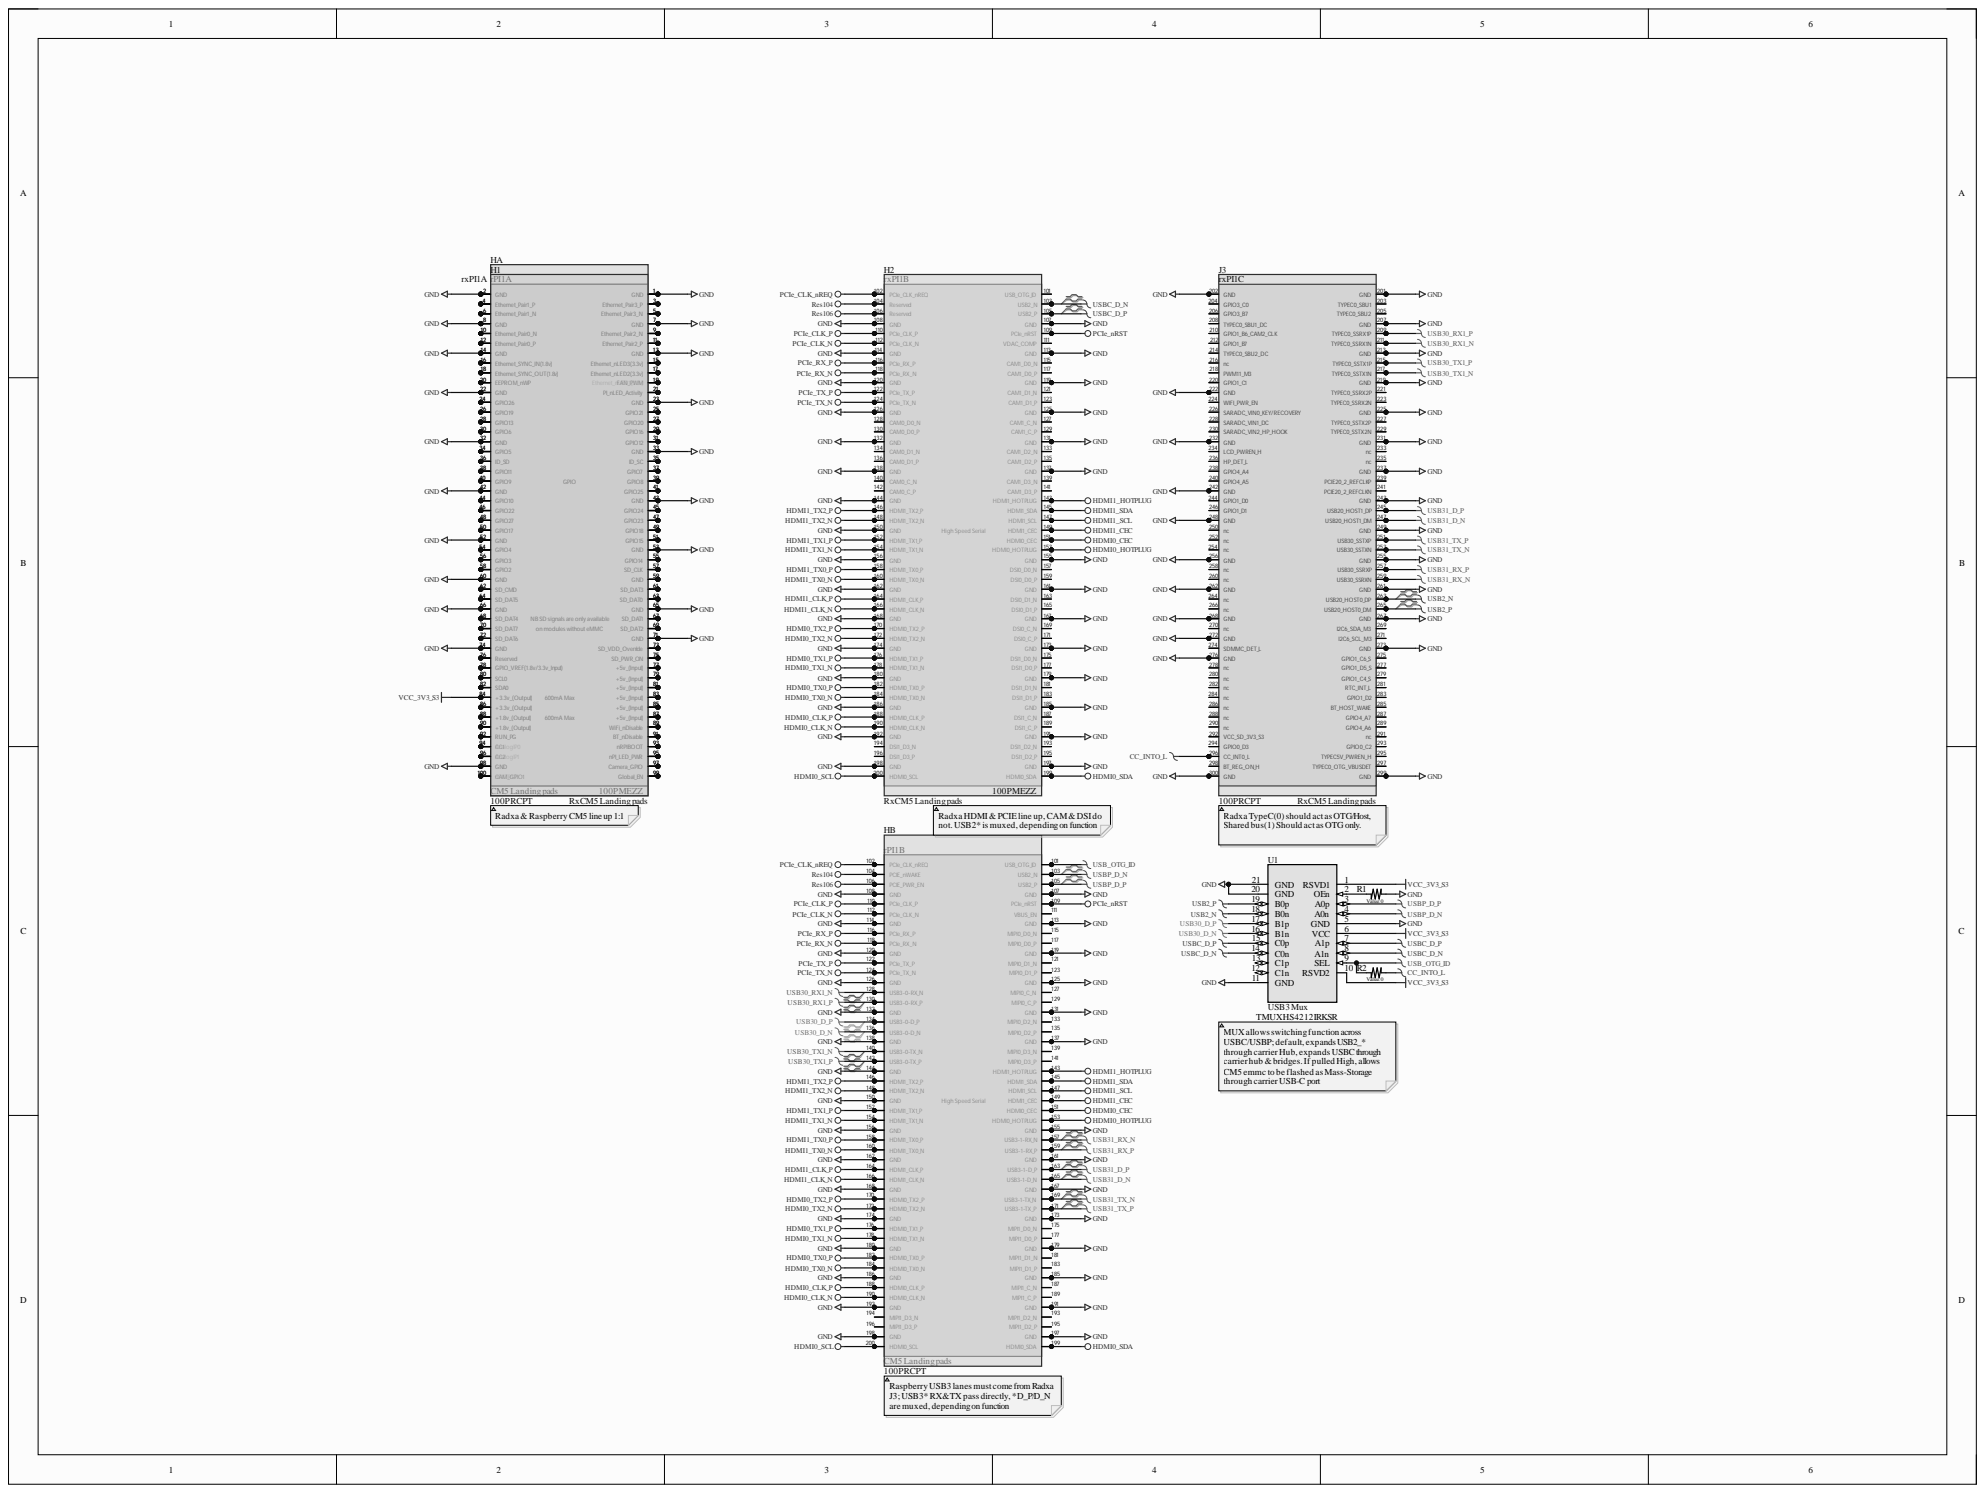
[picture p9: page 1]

NB SD signals are only available

on modules without eMMC

100PRCPT
Radxa TypeC(0) should act asOTG/Host,
Shared bus(1) Should act asOTG only.

not. USB2* ismuxed, dependingon function

MUX allowsswitchingfunction across
USBC/USBP;default, expandsUSB2_*
through carrier Hub, expandsUSBC through
carrier hub &bridges.If pulled High, allows
CM5 emmc to be flashed asMass-Storage
through carrier USB-C port

CM5 Landingpads
Raspberry USB3 lanesmust come fromRadxa
J3;USB3*RX&TX pass directly, *D_P/D_N
aremuxed, dependingon function

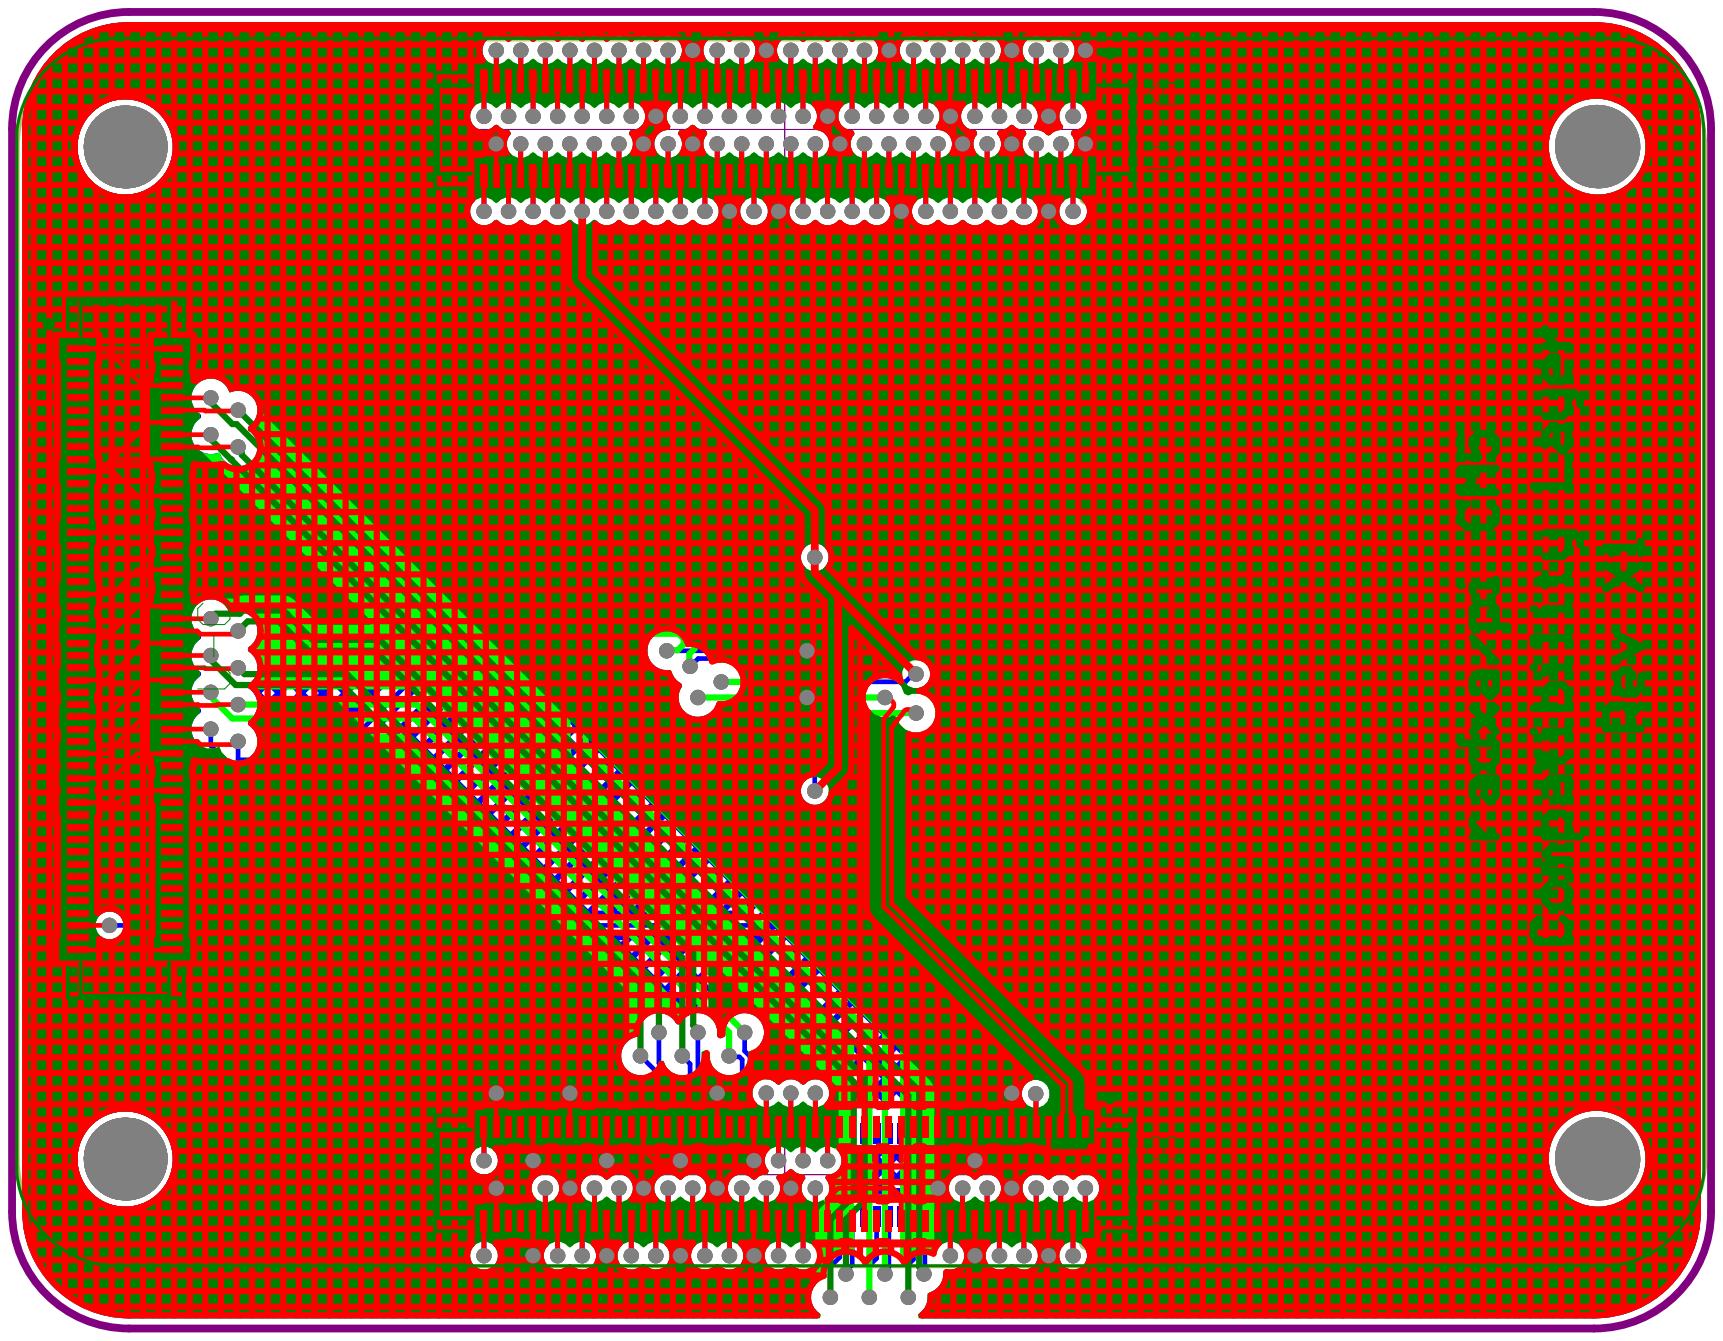
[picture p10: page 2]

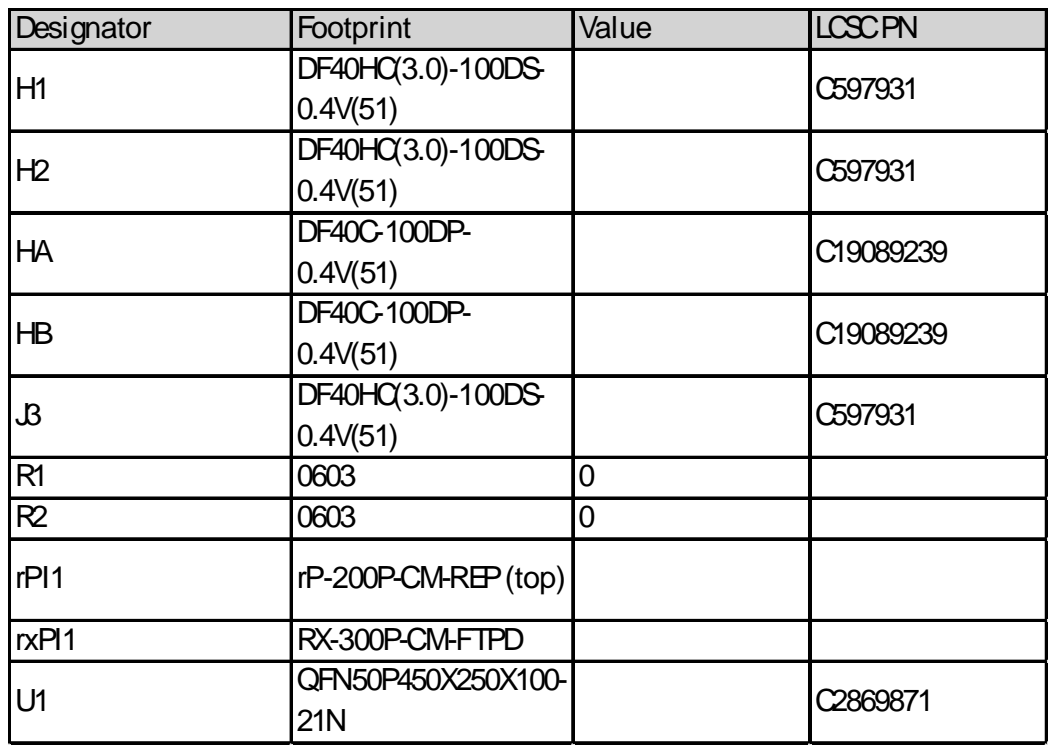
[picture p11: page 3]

Designator | Footprint | Value | LCSCPN
H1 | DF40HC(3.0)-100DS-0.4V(51) | | C597931

R1 | 0603 | 0
R2 | 0603 | 0

rPI1 | rP-200P-CM-REP(top)

rxPI1 | RX-300P-CM-FTPD
U1 | QFN50P450X250X100-21N | | C2869871

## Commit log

2025-05-13 Rename Altium Project/CM5 Adapter.SchDoc to Altium Project/X1/CM5 Adapter.SchDoc
    [CM5 Adapter.SchDoc]
2025-05-13 Rename Altium Project/CM5_Adapter.PcbDoc to Altium Project/X1/CM5_Adapter.PcbDoc
    [CM5_Adapter.PcbDoc]
2025-05-13 Update and rename Altium Project/rX-rP.X1.PrjPcb to Altium Project/X1/rX-rP.X1.PrjPcb
    [rX-rP.X1.PrjPcb]
2025-09-18 Update README.md
    include images of current design
2025-09-22 Upload X2 design files
    [CM5 Adapter.SchDoc, rX-rP.X2.PrjPcb]
2025-10-17 Add update log for X2 and CM5 testing
    Documented the arrival of X2 samples and CM5, along with initial testing results and issues encountered with USB ports.
2026-02-20 upload X4 design files
    [CM5 Adapter.SchDoc, rX-rP.X4.PrjPcb]
2026-02-20 Update README with X4 design and X3 sample status
    Documented design changes for X4 and status of X3 samples.
